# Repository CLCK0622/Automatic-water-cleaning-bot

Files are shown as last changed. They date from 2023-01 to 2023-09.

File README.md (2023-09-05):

# Automatic watercleaning bot

An automatic water cleaning bot made with Arduino Uno3.

### What can it do?

It is equipped with an AI cam made by DFRobot, and can track and identify the floating rubbish. 

### How to use?

Using the same hardware and assemble them on yourself. And download the Arduino IDE on [website](https://www.arduino.cc/en/software), deploy the code to your bot, then enjoy. 

### Contribution

This work is incomplete and still need to be improved. If you are interested and also glad to help, welcome to raise issues, or fork it then create a pull request.

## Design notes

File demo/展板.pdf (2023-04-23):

研究背景 | 项目总结

## 研究过程及实验结论

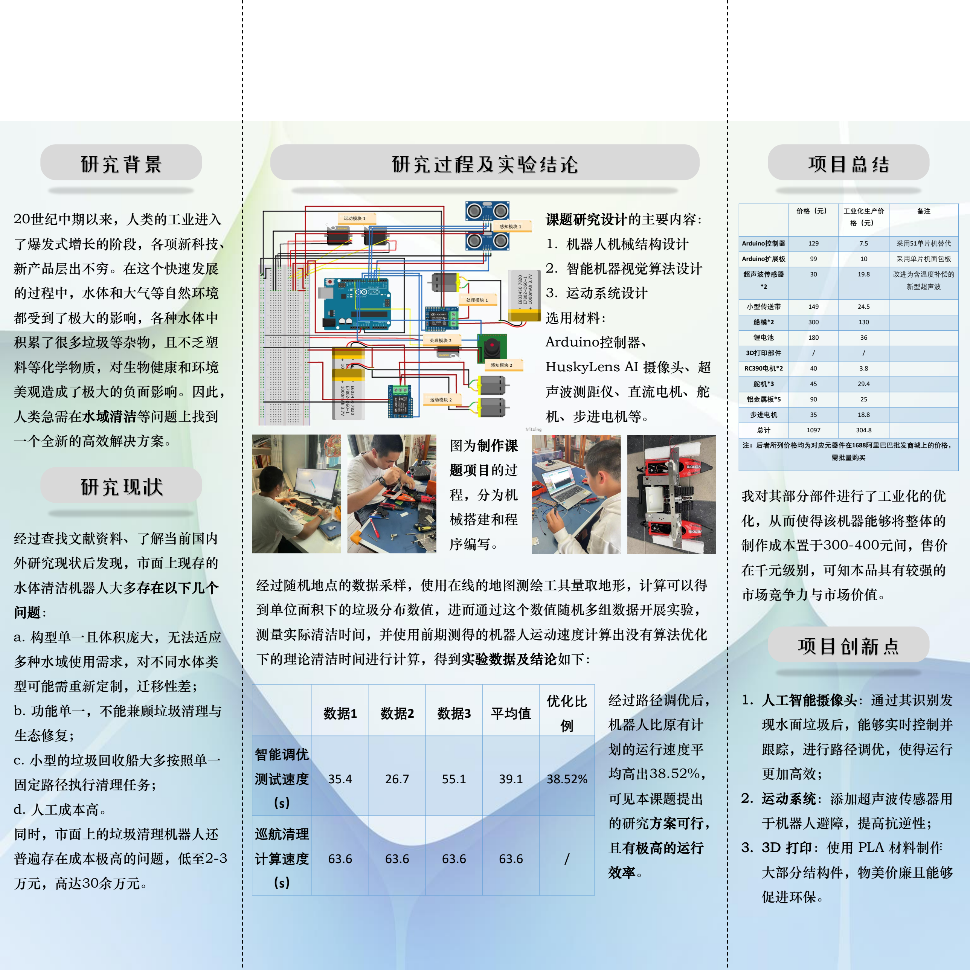
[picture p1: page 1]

20世纪中期以来，人类的工业进入

了爆发式增长的阶段，各项新科技、

新产品层出不穷。在这个快速发展

的过程中，水体和大气等自然环境

都受到了极大的影响，各种水体中

积累了很多垃圾等杂物，且不乏塑

料等化学物质，对生物健康和环境

美观造成了极大的负面影响。因此，

人类急需在水域清洁等问题上找到

一个全新的高效解决方案。

## 研究现状

经过查找文献资料、了解当前国内

外研究现状后发现，市面上现存的

水体清洁机器人大多存在以下几个

问题：

a. 构型单一且体积庞大，无法适应

多种水域使用需求，对不同水体类

型可能需重新定制，迁移性差；

b. 功能单一，不能兼顾垃圾清理与

生态修复；

c. 小型的垃圾回收船大多按照单一

固定路径执行清理任务；

d. 人工成本高。

同时，市面上的垃圾清理机器人还

普遍存在成本极高的问题，低至2-3

万元，高达30余万元。

课题研究设计的主要内容：

1. 机器人机械结构设计
2. 智能机器视觉算法设计
3. 运动系统设计

选用材料：

Arduino控制器、

HuskyLens AI 摄像头、超

声波测距仪、直流电机、舵

机、步进电机等。

图为制作课

题项目的过

程，分为机

械搭建和程

序编写。

经过随机地点的数据采样，使用在线的地图测绘工具量取地形，计算可以得

到单位面积下的垃圾分布数值，进而通过这个数值随机多组数据开展实验，

测量实际清洁时间，并使用前期测得的机器人运动速度计算出没有算法优化

下的理论清洁时间进行计算，得到实验数据及结论如下：

| 数据1 | 数据2 | 数据3 | 平均值 | 优化比 例
智能调优 测试速度 （s） | 35.4 | 26.7 | 55.1 | 39.1 | 38.52%
巡航清理 计算速度 （s） | 63.6 | 63.6 | 63.6 | 63.6 | /

经过路径调优后，

机器人比原有计

划的运行速度平

均高出38.52%，

可见本课题提出

的研究方案可行，

且有极高的运行

效率。

| 价格（元） | 工业化生产价 格（元） | 备注
Arduino控制器 | 129 | 7.5 | 采用51单片机替代
Arduino扩展板 | 99 | 10 | 采用单片机面包板
超声波传感器 *2 | 30 | 19.8 | 改进为含温度补偿的 新型超声波
小型传送带 | 149 | 24.5
船模*2 | 300 | 130
锂电池 | 180 | 36
3D打印部件 | / | /
RC390电机*2 | 40 | 3.8
舵机*3 | 45 | 29.4
铝金属板*5 | 90 | 25
步进电机 | 35 | 18.8
总计 | 1097 | 304.8

注：后者所列价格均为对应元器件在1688阿里巴巴批发商城上的价格， 需批量购买

我对其部分部件进行了工业化的优

化，从而使得该机器能够将整体的

制作成本置于300-400元间，售价

在千元级别，可知本品具有较强的

市场竞争力与市场价值。

## 项目创新点

1. 人工智能摄像头：通过其识别发

现水面垃圾后，能够实时控制并

跟踪，进行路径调优，使得运行

更加高效；

2. 运动系统：添加超声波传感器用

于机器人避障，提高抗逆性；

3. 3D 打印：使用 PLA 材料制作

大部分结构件，物美价廉且能够

促进环保。

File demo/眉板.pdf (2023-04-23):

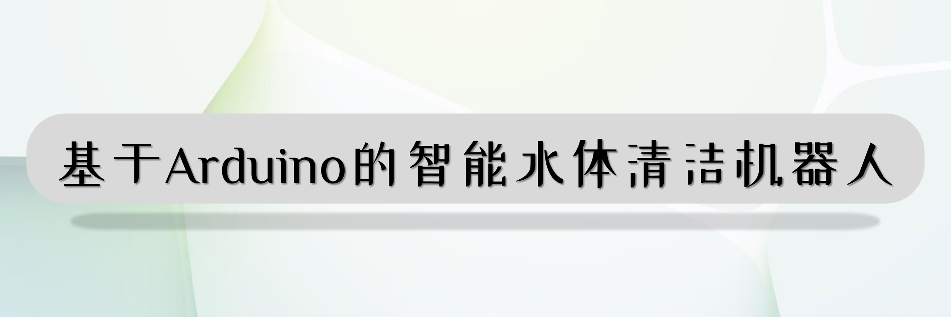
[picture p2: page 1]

基于Arduino的智能水体清洁机器人

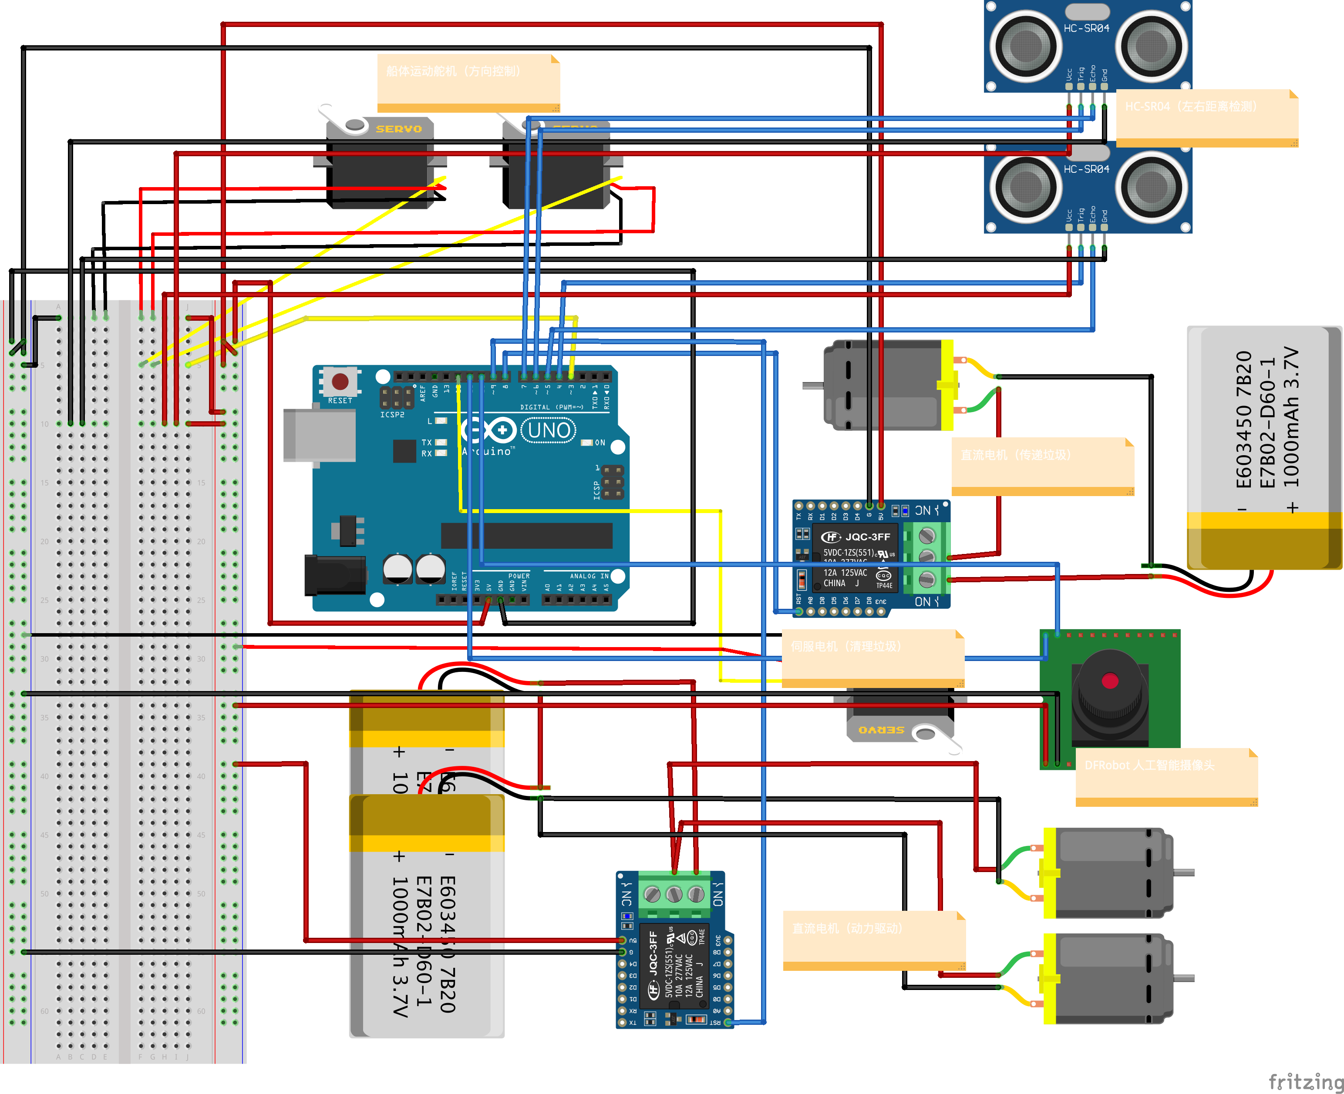
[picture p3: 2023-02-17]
demo/circuitDiagram.png

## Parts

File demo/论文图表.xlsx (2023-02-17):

河流宽度 | 3米 | 5米 | 6米 | 9米 | 13米
垃圾数量 | 4 | 2 | 1 | 2 | 1
元器件名称 | 价格（元） | 工业化生产价格（元） | 备注
Arduino控制器 | 129 | 7.5 | 采用51单片机替代
Arduino扩展板 | 99 | 10 | 采用单片机面包板
超声波传感器*2 | 30 | 19.8 | 改进为含温度补偿的新型超声波
小型传送带 | 149 | 24.5
船模*2 | 300 | 130
锂电池 | 180 | 36
3D打印部件 | / | /
RC390电机*2 | 40 | 3.8
舵机*3 | 45 | 29.4
铝金属板*5 | 90 | 25
步进电机 | 35 | 18.8
总计 | 1097 | 304.8
注：后者所列价格均为对应元器件在1688阿里巴巴批发商城上的价格，需批量购买

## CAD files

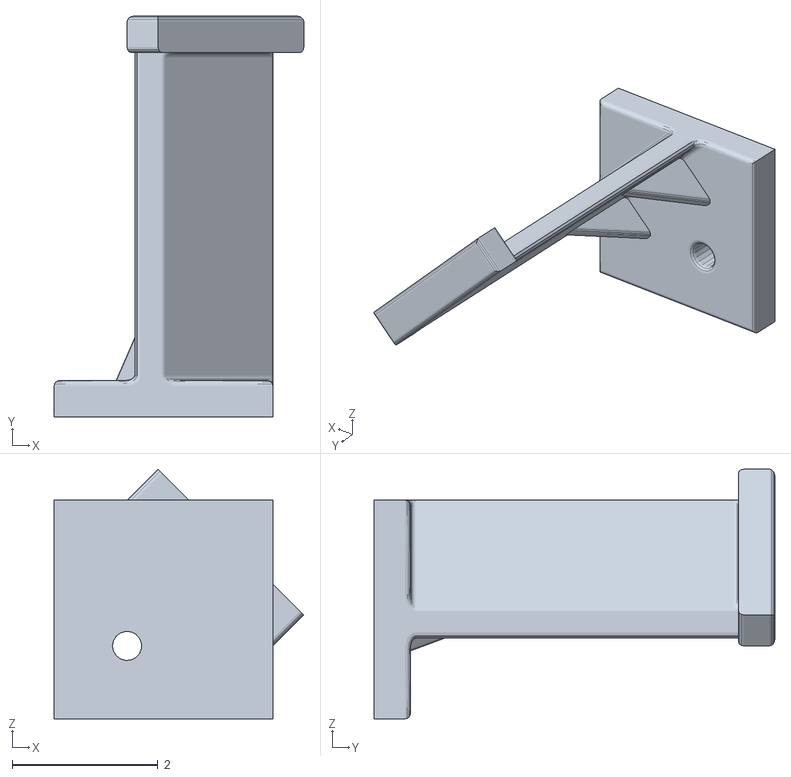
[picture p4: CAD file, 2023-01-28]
CADs/HC-SR04-support.stl
3.42 x 5.50 x 3.42

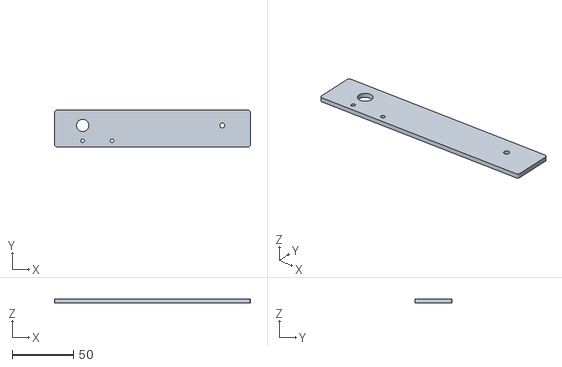
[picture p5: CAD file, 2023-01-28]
CADs/传送带支架.STL
160.0 x 30.0 x 3.00

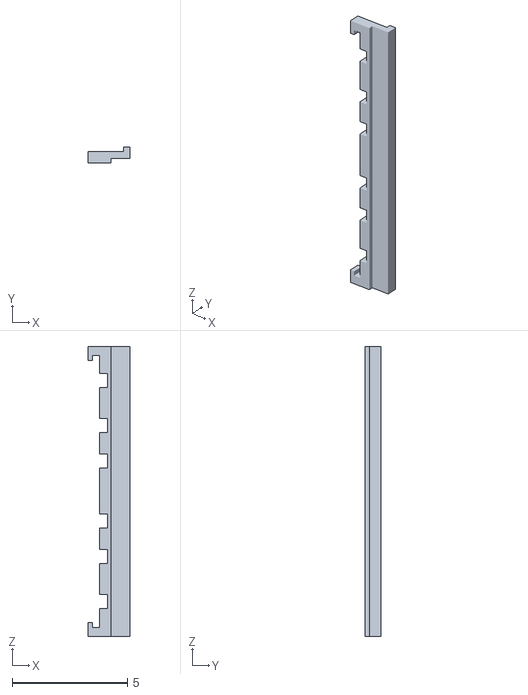
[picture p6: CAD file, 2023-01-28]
CADs/scratcher.stl
1.84 x 0.7 x 12.6

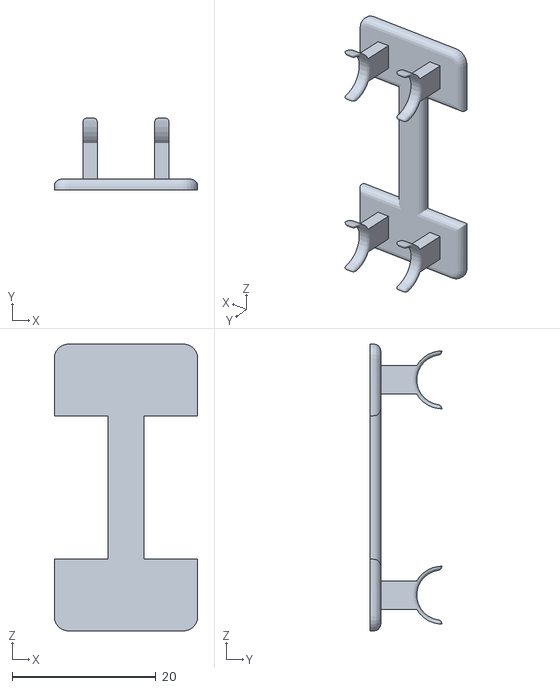
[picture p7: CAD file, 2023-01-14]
CADs/support.stl
20.0 x 10.0 x 40.0

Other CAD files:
CADs/HC-SR04-support.ipt
CADs/OldVersions/HC-SR04-support.0001.ipt
CADs/OldVersions/scratcher.0004.ipt
CADs/scratcher.ipt
CADs/support.ipt

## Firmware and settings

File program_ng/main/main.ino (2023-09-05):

#include <Arduino.h>
#include "HC_SR04.h"
#include "HUSKYLENS.h"
#include "SoftwareSerial.h"
#include <Servo.h>

HC_SR04 disLeft, disRight;
HUSKYLENS lens;
Servo ang, box;

// here to declare const variables:
const int servoPin = 3;
const int boxPin = 5;
const int motorPin = 7;
const int passerPin = 9;

void setup() {
  // put your setup code here, to run once:
  Serial.begin(115200);
  
  Wire.begin();
  while (!lens.begin(Wire)) {
    Serial.println(F("Begin failed!"));
    Serial.println(F("Please check!"));
    delay(100);
  }
  
  disLeft.init(9, 10);
  disRight.init(12, 13);

  pinMode(servoPin, OUTPUT);
  pinMode(motorPin, OUTPUT);
  pinMode(passerPin, OUTPUT);
  pinMode(boxPin, OUTPUT);

  ang.attach(servoPin, 500, 2500);
  box.attach(boxPin, 500, 2500);
  ang.write(110);
  box.write(90);

  Serial.println("Init successfully! ");
}

void loop() {
  // initialize the variables here:
  int offset = 5;
  HUSKYLENSResult result;

  // put your main code here, to run repeatedly:
  digitalWrite(passerPin, HIGH);

  if (!tracked) {
    forward();
    while ((disLeft.get_dis() > 5 && disLeft.get_dis() < 150) || (disRight.get_dis() > 5 && disRight.get_dis() < 150)) {
      if (disLeft.get_dis() > 150) {
        left();
      } else if (disRight.get_dis() > 150) {
        right();
      } else {
        stop();
      }
    }
  } else {
    while (getTargetX < -offset) {
      left();
    }
    while (getTargetX > offset) {
      right();
    }
  }

  if (!lens.request()) {
    Serial.println(F("Fail to request data from HUSKYLENS, check the connection! "));
  } else if (!lens.isLearned()) {
    Serial.println(F("Nothing learned, press learn button on the HUSKYLENS first! "));
  } else if (!lens.available()) {
    Serial.println(F("No target found! "));
  } else {
    if (lens.available()) {
      result = lens.read();
    }
  }
}

void printResult(HUSKYLENSResult result) {
  if (result.command == COMMAND_RETURN_BLOCK) {
    Serial.println(String() + F("Block:xCenter=") + result.xCenter + F(", yCenter=") + result.yCenter);
  } else {
    Serial.println("Object unknown! ");
  }
}

void forward() {
  Serial.println("forward");
  digitalWrite(motorPin, HIGH);
  ang.write(110);
  return ;
}

void stop() {
  Serial.println("stop");
  digitalWrite(motorPin, LOW);
  ang.write(110);
  return ;
}

void left() {
  Serial.println("left");
  ang.write(80);
  return ;
}

void right() {
  Serial.println("right");
  ang.write(110);
  return ;
}

bool tracked() {
  if (lens.available()) {
    return true;
  } else {
    return false;
  }
}

double getTargetX(HUSKYLENSResult result) {
  if (tracked() && result.command == COMMAND_RETURN_BLOCK) {
    return result.xCenter;
  }
  return 0;
}

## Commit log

2023-01-14 update support CAD
    [support.ipt, support.stl]
2023-01-26 upd CADs
    [HC-SR04-support.0001.ipt, HC-SR04-support.ipt, HC-SR04-support.stl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]
2023-01-28 upd circuit
    [circuitDiagram.fzz]
2023-02-05 upd prop
2023-02-17 adjust prog
    [论文图表.xlsx]
2023-03-02 add presentation board
2023-09-05 dir change
    [circuitDiagram.fzz, 论文图表.xlsx]
